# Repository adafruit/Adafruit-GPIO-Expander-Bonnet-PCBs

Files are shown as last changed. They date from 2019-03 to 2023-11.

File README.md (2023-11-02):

## Adafruit GPIO Expander Bonnet PCB

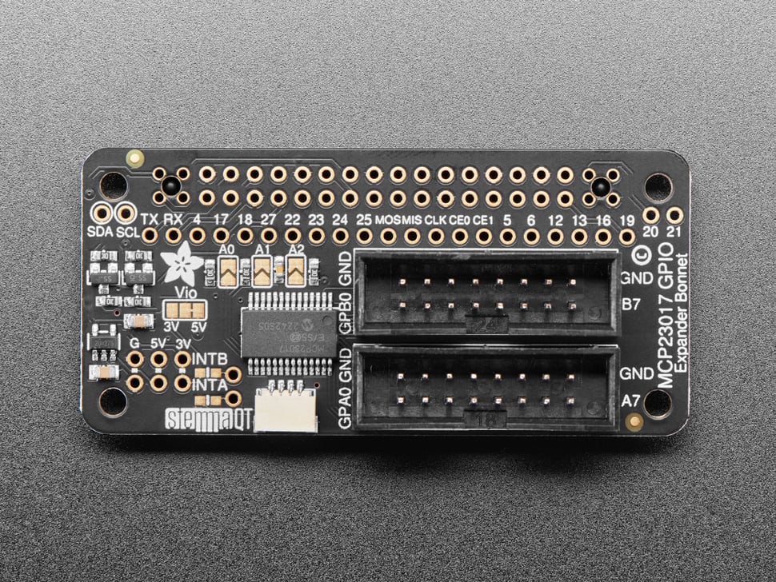
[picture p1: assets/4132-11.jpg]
<a href="http://www.adafruit.com/products/4132"><br/>
Click here to purchase one from the Adafruit shop</a>

PCB files for the Adafruit GPIO Expander Bonnet. Format is EagleCAD schematic and board layout
* https://www.adafruit.com/product/4132

### Description

The Raspberry Pi is an amazing single board computer - and one of the best parts is that GPIO connector! 40 pins of digital goodness you can twiddle to control LEDs, sensors, buttons, radios, displays - just about any device you can imagine. This Adafruit GPIO Expander Bonnet will give you even more digital deliciousness - 16 more digital input/output pins are yours for any desire you have. The outputs are grouped into two 16-pin connectors that have a matching ground pin. You can set each pin to be a digital output (high or low) or as an input, with an internal pull-up if you like!

Simply pop the Bonnet on top of your Pi, the circuitry connects to the SDA/SCL I2C pins for control. The MCP23017 chip converts our Python commands to pin instructions.

When used as an output, each pin can supply up to 20mA (current clamped) - so you can drive LEDs directly. The datasheet recommends you keep the total current draw to under 125mA for the whole chip. We set up the expander chip for 5V logic by default (the I2C is level shifted so that's 3V logic). We did that so you can drive white, blue or green LEDs that sometimes aren't too happy with 3.3V logic. Or, you can cut/solder a jumper to change it to 3.3V logic.

When used as an input, you can set up a pull-up resistor so buttons and switches don't need extra resistors - just wire the pin to one side and ground to the other! There's interrupt capabilities on the chip, and two IRQ pins (INTA and INTB) you can solder a wire to, if you want to have a quick way of telling if any of the GPIO's changed.

By soldering close the address select jumpers, you can change the address from 0x20 up to 0x27. So, if you wanted to, you could have up to 8 bonnets for 128 total GPIO.

Comes as an assembled and tested Bonnet with slim 2x20 header connector on the bottom. We provide 2 sets of 16-pin IDC sockets, you can solder these in or leave them off for a slim setup. [Follow our guide to use our CircuitPython library with Python 3 for fast and easy setup and configuration, you'll be running in under 5 minutes.](https://learn.adafruit.com/gpio-expander-bonnet/overview)

<b>As of October 31, 2023</b> - We've added an on-board Stemma QT port for easy plug-n-play of I2C sensors and devices. The board also now comes with the two IDC socket headers pre-soldered. Lastly, we've also updated it with Adafruit Pinguin to make a lovely and legible silkscreen

### License

Adafruit invests time and resources providing this open source design, please support Adafruit and open-source hardware by purchasing products from [Adafruit](https://www.adafruit.com)!

Designed by Limor Fried/Ladyada for Adafruit Industries.

Creative Commons Attribution/Share-Alike, all text above must be included in any redistribution. See license.txt for additional details.

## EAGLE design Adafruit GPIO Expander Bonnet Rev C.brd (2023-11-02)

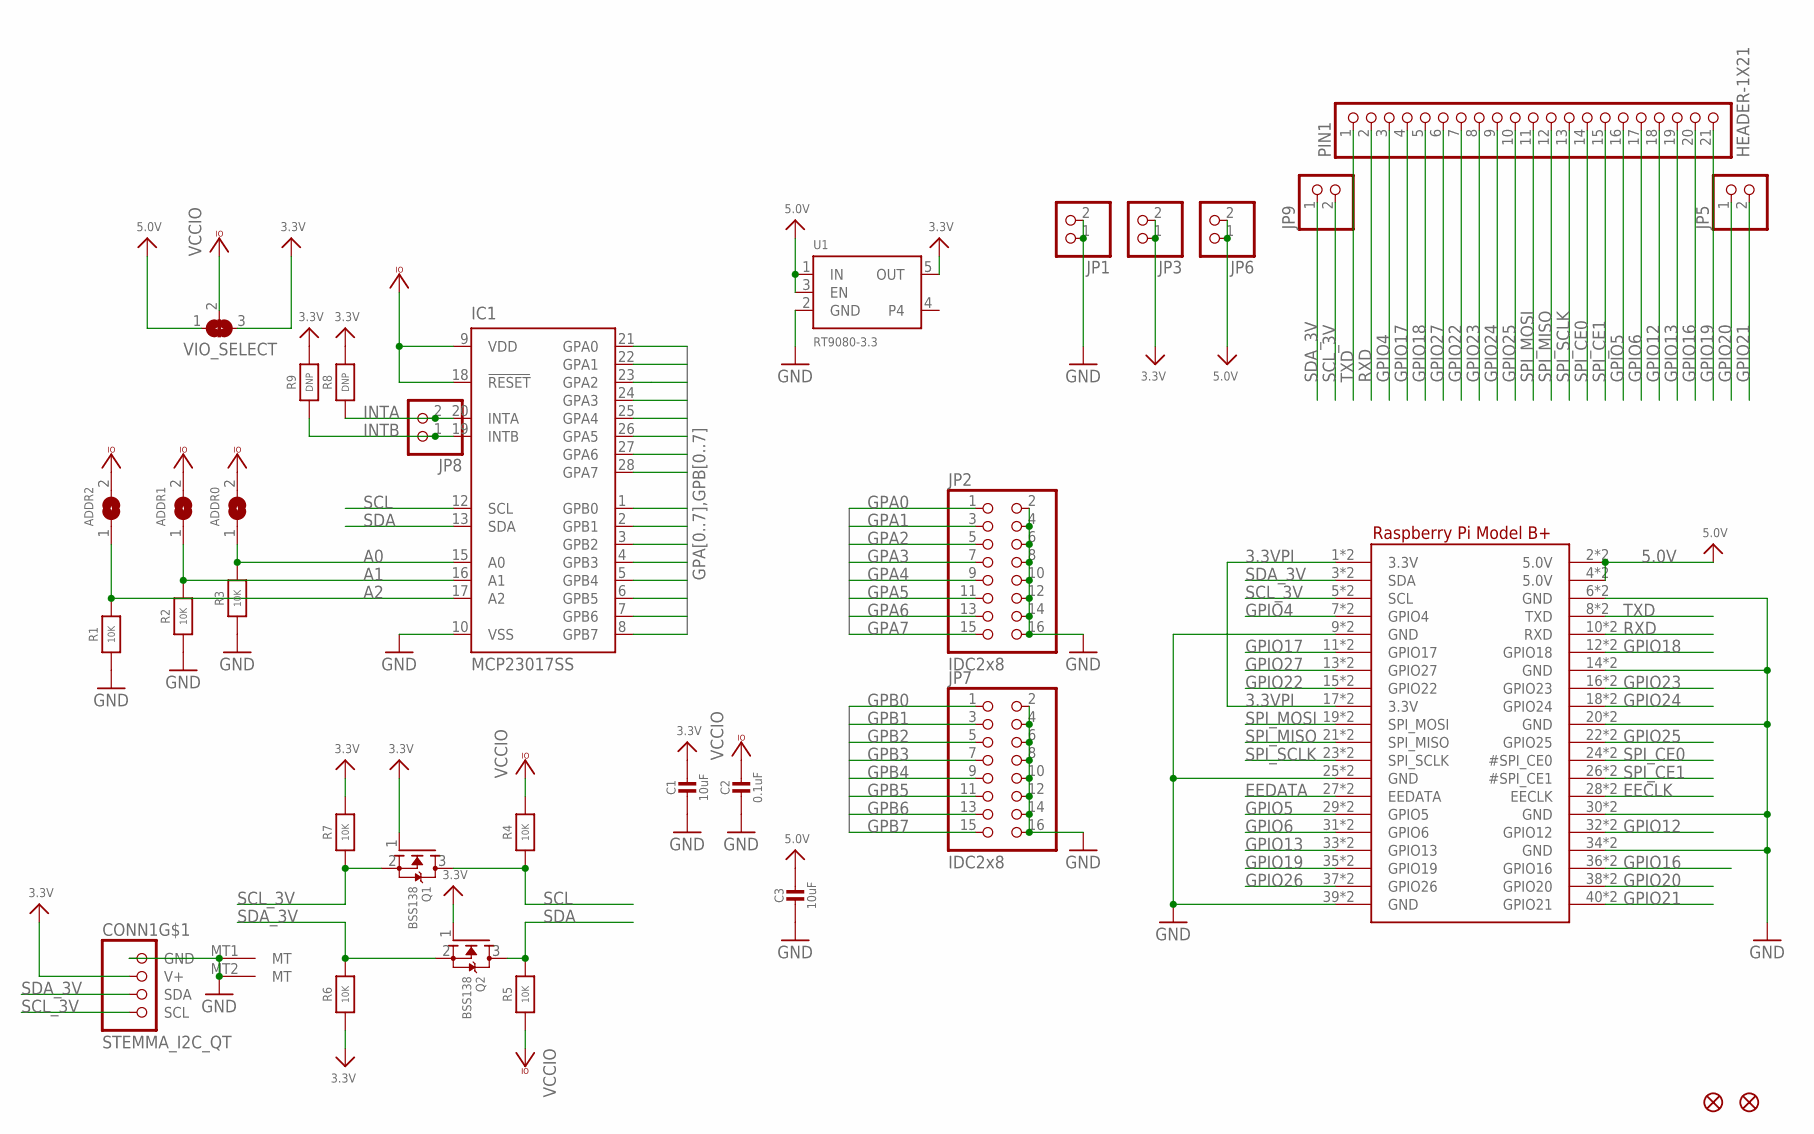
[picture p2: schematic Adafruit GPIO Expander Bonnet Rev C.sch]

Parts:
ADDR0, ADDR1, ADDR2: SOLDERJUMPER; SOLDERJUMPER_ARROW_NOPASTE
C1, C3: 10uF; 0805-NO
C2: 0.1uF; 0603-NO
CONN1: STEMMA_I2C_QT; JST_SH4
FID1, FID2: FIDUCIAL_1MM
IC1: MCP23017SS; SSOP28
JP1, JP3, JP5, JP6, JP8, JP9: HEADER-1X2ROUND; 1X02_ROUND
JP2, JP7: IDC2x8; 2X08_SHROUDED
PIN1: HEADER-1X21; 1X21_ROUND_70MIL
Q1, Q2: BSS138; SOT23-WIDE
R1, R2, R3, R4, R5, R6, R7: 10K; 0603-NO
R8, R9: DNP; 0603-NO
RPI1: RASPBERRYPI_BPLUS_BONNET_THMSMT; PI_BONNET_THMSMT
U1: RT9080-3.3; SOT23-5; JLC_ROTATION 0
VIO_SELECT: SOLDERJUMPER_2WAY; SOLDERJUMPER_2WAY_OPEN_NOPASTE

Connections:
3.3V: C1.1, CONN1.2 (V+), JP3.1, JP3.2, Q1.1 (G), Q2.1 (G), R6.1, R7.2, R8.2, R9.2, U1.5 (OUT), VIO_SELECT.3
3.3VPI: RPI1.1 (3.3V), RPI1.17 (3.3V), RPI1.S1 (3.3V), RPI1.S17 (3.3V)
5.0V: C3.1, JP6.1, JP6.2, RPI1.2 (5.0V), RPI1.4 (5.0V), RPI1.S2 (5.0V), RPI1.S4 (5.0V), U1.1 (IN), U1.3 (EN), VIO_SELECT.1
A0: ADDR0.1, IC1.15 (A0), R3.2
A1: ADDR1.1, IC1.16 (A1), R2.2
A2: ADDR2.1, IC1.17 (A2), R1.2
EECLK: RPI1.28 (EECLK), RPI1.S28 (EECLK)
EEDATA: RPI1.27 (EEDATA), RPI1.S27 (EEDATA)
GND: C1.2, C2.2, C3.2, CONN1.1 (GND), CONN1.MT1 (MT), CONN1.MT2 (MT), IC1.10 (VSS), JP1.1, JP1.2, JP2.2, JP2.4, JP2.6, JP2.8, JP2.10, JP2.12, JP2.14, JP2.16, JP7.2, JP7.4, JP7.6, JP7.8, JP7.10, JP7.12, JP7.14, JP7.16, R1.1, R2.1, R3.1, RPI1.6 (GND), RPI1.9 (GND), RPI1.14 (GND), RPI1.20 (GND), RPI1.25 (GND), RPI1.30 (GND), RPI1.34 (GND), RPI1.39 (GND), RPI1.S6 (GND), RPI1.S9 (GND), RPI1.S14 (GND), RPI1.S20 (GND), RPI1.S25 (GND), RPI1.S30 (GND), RPI1.S34 (GND), RPI1.S39 (GND), U1.2 (GND)
GPA0: IC1.21 (GPA0), JP2.1
GPA1: IC1.22 (GPA1), JP2.3
GPA2: IC1.23 (GPA2), JP2.5
GPA3: IC1.24 (GPA3), JP2.7
GPA4: IC1.25 (GPA4), JP2.9
GPA5: IC1.26 (GPA5), JP2.11
GPA6: IC1.27 (GPA6), JP2.13
GPA7: IC1.28 (GPA7), JP2.15
GPB0: IC1.1 (GPB0), JP7.1
GPB1: IC1.2 (GPB1), JP7.3
GPB2: IC1.3 (GPB2), JP7.5
GPB3: IC1.4 (GPB3), JP7.7
GPB4: IC1.5 (GPB4), JP7.9
GPB5: IC1.6 (GPB5), JP7.11
GPB6: IC1.7 (GPB6), JP7.13
GPB7: IC1.8 (GPB7), JP7.15
GPIO4: PIN1.3, RPI1.7 (GPIO4), RPI1.S7 (GPIO4)
GPIO5: PIN1.16, RPI1.29 (GPIO5), RPI1.S29 (GPIO5)
GPIO6: PIN1.17, RPI1.31 (GPIO6), RPI1.S31 (GPIO6)
GPIO12: PIN1.18, RPI1.32 (GPIO12), RPI1.S32 (GPIO12)
GPIO13: PIN1.19, RPI1.33 (GPIO13), RPI1.S33 (GPIO13)
GPIO16: PIN1.20, RPI1.36 (GPIO16), RPI1.S36 (GPIO16)
GPIO17: PIN1.4, RPI1.11 (GPIO17), RPI1.S11 (GPIO17)
GPIO18: PIN1.5, RPI1.12 (GPIO18), RPI1.S12 (GPIO18)
GPIO19: PIN1.21, RPI1.35 (GPIO19), RPI1.S35 (GPIO19)
GPIO20: JP5.1, RPI1.38 (GPIO20), RPI1.S38 (GPIO20)
GPIO21: JP5.2, RPI1.40 (GPIO21), RPI1.S40 (GPIO21)
GPIO22: PIN1.7, RPI1.15 (GPIO22), RPI1.S15 (GPIO22)
GPIO23: PIN1.8, RPI1.16 (GPIO23), RPI1.S16 (GPIO23)
GPIO24: PIN1.9, RPI1.18 (GPIO24), RPI1.S18 (GPIO24)
GPIO25: PIN1.10, RPI1.22 (GPIO25), RPI1.S22 (GPIO25)
GPIO26: RPI1.37 (GPIO26), RPI1.S37 (GPIO26)
GPIO27: PIN1.6, RPI1.13 (GPIO27), RPI1.S13 (GPIO27)
INTA: IC1.20 (INTA), JP8.2, R8.1
INTB: IC1.19 (INTB), JP8.1, R9.1
RXD: PIN1.2, RPI1.10 (RXD), RPI1.S10 (RXD)
SCL: IC1.12 (SCL), Q1.3 (D), R4.1
SCL_3V: CONN1.4 (SCL), JP9.2, Q1.2 (S), R7.1, RPI1.5 (SCL), RPI1.S5 (SCL)
SDA: IC1.13 (SDA), Q2.3 (D), R5.2
SDA_3V: CONN1.3 (SDA), JP9.1, Q2.2 (S), R6.2, RPI1.3 (SDA), RPI1.S3 (SDA)
SPI_CE0: PIN1.14, RPI1.24 (#SPI_CE0), RPI1.S24 (#SPI_CE0)
SPI_CE1: PIN1.15, RPI1.26 (#SPI_CE1), RPI1.S26 (#SPI_CE1)
SPI_MISO: PIN1.12, RPI1.21 (SPI_MISO), RPI1.S21 (SPI_MISO)
SPI_MOSI: PIN1.11, RPI1.19 (SPI_MOSI), RPI1.S19 (SPI_MOSI)
SPI_SCLK: PIN1.13, RPI1.23 (SPI_SCLK), RPI1.S23 (SPI_SCLK)
TXD: PIN1.1, RPI1.8 (TXD), RPI1.S8 (TXD)
VCCIO: ADDR0.2, ADDR1.2, ADDR2.2, C2.1, IC1.9 (VDD), IC1.18 (!RESET), R4.2, R5.1, VIO_SELECT.2

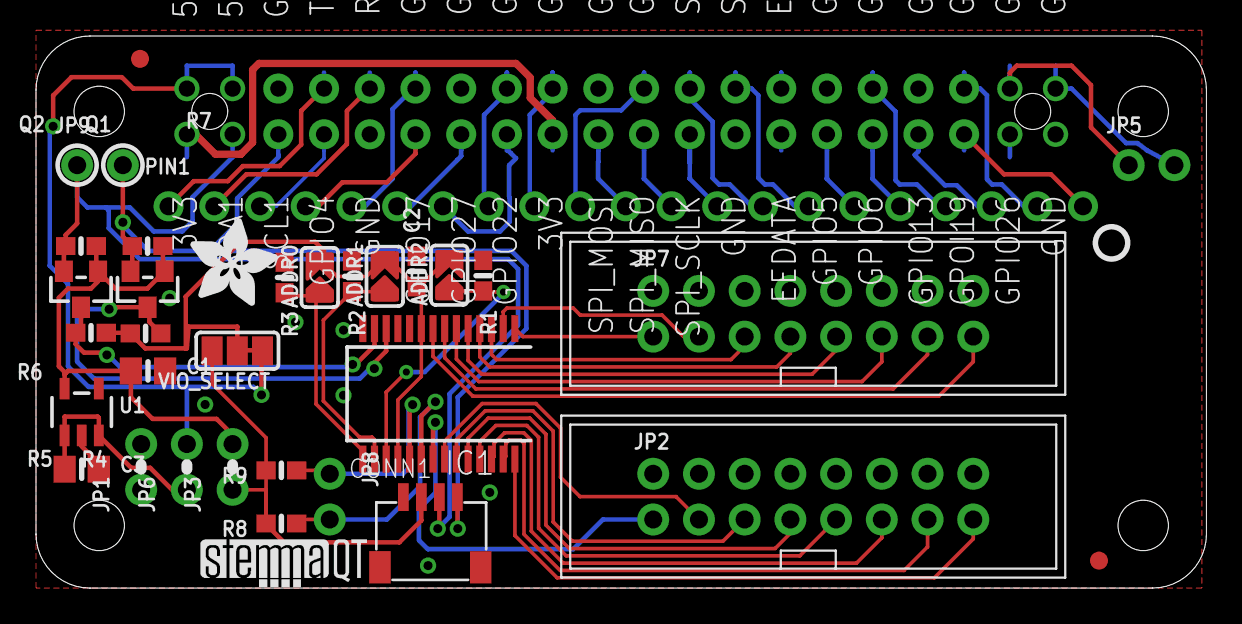
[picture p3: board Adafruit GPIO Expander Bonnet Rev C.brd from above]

Board: 2 copper layers, 65.0 x 30.7 mm, 100 parts (0 on the bottom side), 56 nets.

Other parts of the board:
PLABEL0: PLABEL0
PLABEL1: PLABEL1
PLABEL2: PLABEL2
PLABEL3: PLABEL3
PLABEL4: PLABEL4
PLABEL5: PLABEL5
PLABEL6: PLABEL6
PLABEL7: PLABEL7
PLABEL8: PLABEL8
PLABEL9: PLABEL9
PLABEL10: PLABEL10
PLABEL11: PLABEL11
PLABEL12: PLABEL12
PLABEL13: PLABEL13
PLABEL14: PLABEL14
PLABEL15: PLABEL15
PLABEL16: PLABEL16
PLABEL17: PLABEL17
PLABEL18: PLABEL18
PLABEL19: PLABEL19
PLABEL20: PLABEL20
PLABEL21: PLABEL21
PLABEL22: PLABEL22
PLABEL23: PLABEL23
PLABEL24: PLABEL24
PLABEL25: PLABEL25
PLABEL26: PLABEL26
PLABEL27: PLABEL27
PLABEL28: PLABEL28
PLABEL29: PLABEL29
PLABEL30: PLABEL30
PLABEL31: PLABEL31
PLABEL32: PLABEL32
PLABEL33: PLABEL33
PLABEL34: PLABEL34
PLABEL35: PLABEL35
PLABEL36: PLABEL36
PLABEL37: PLABEL37
PLABEL38: PLABEL38
PLABEL39: PLABEL39
PLABEL40: PLABEL40
PLABEL41: PLABEL41
PLABEL42: PLABEL42
PLABEL43: PLABEL43
PLABEL44: PLABEL44
PLABEL45: PLABEL45
PLABEL46: PLABEL46
PLABEL47: PLABEL47
PLABEL48: PLABEL48
PLABEL49: PLABEL49
PLABEL50: PLABEL50
PLABEL51: PLABEL51
PLABEL52: PLABEL52
PLABEL53: PLABEL53
PLABEL54: PLABEL54
PLABEL55: PLABEL55
PLABEL56: PLABEL56
PLABEL57: PLABEL57
PLABEL58: PLABEL58
PLABEL59: PLABEL59
PLABEL60: PLABEL60
PLABEL61: PLABEL61
PLABEL62: PLABEL62
PLABEL63: PLABEL63
U$12: ADAFRUIT_5MM
U$13: PCBFEAT-REV-040
U$19: STEMMAQT

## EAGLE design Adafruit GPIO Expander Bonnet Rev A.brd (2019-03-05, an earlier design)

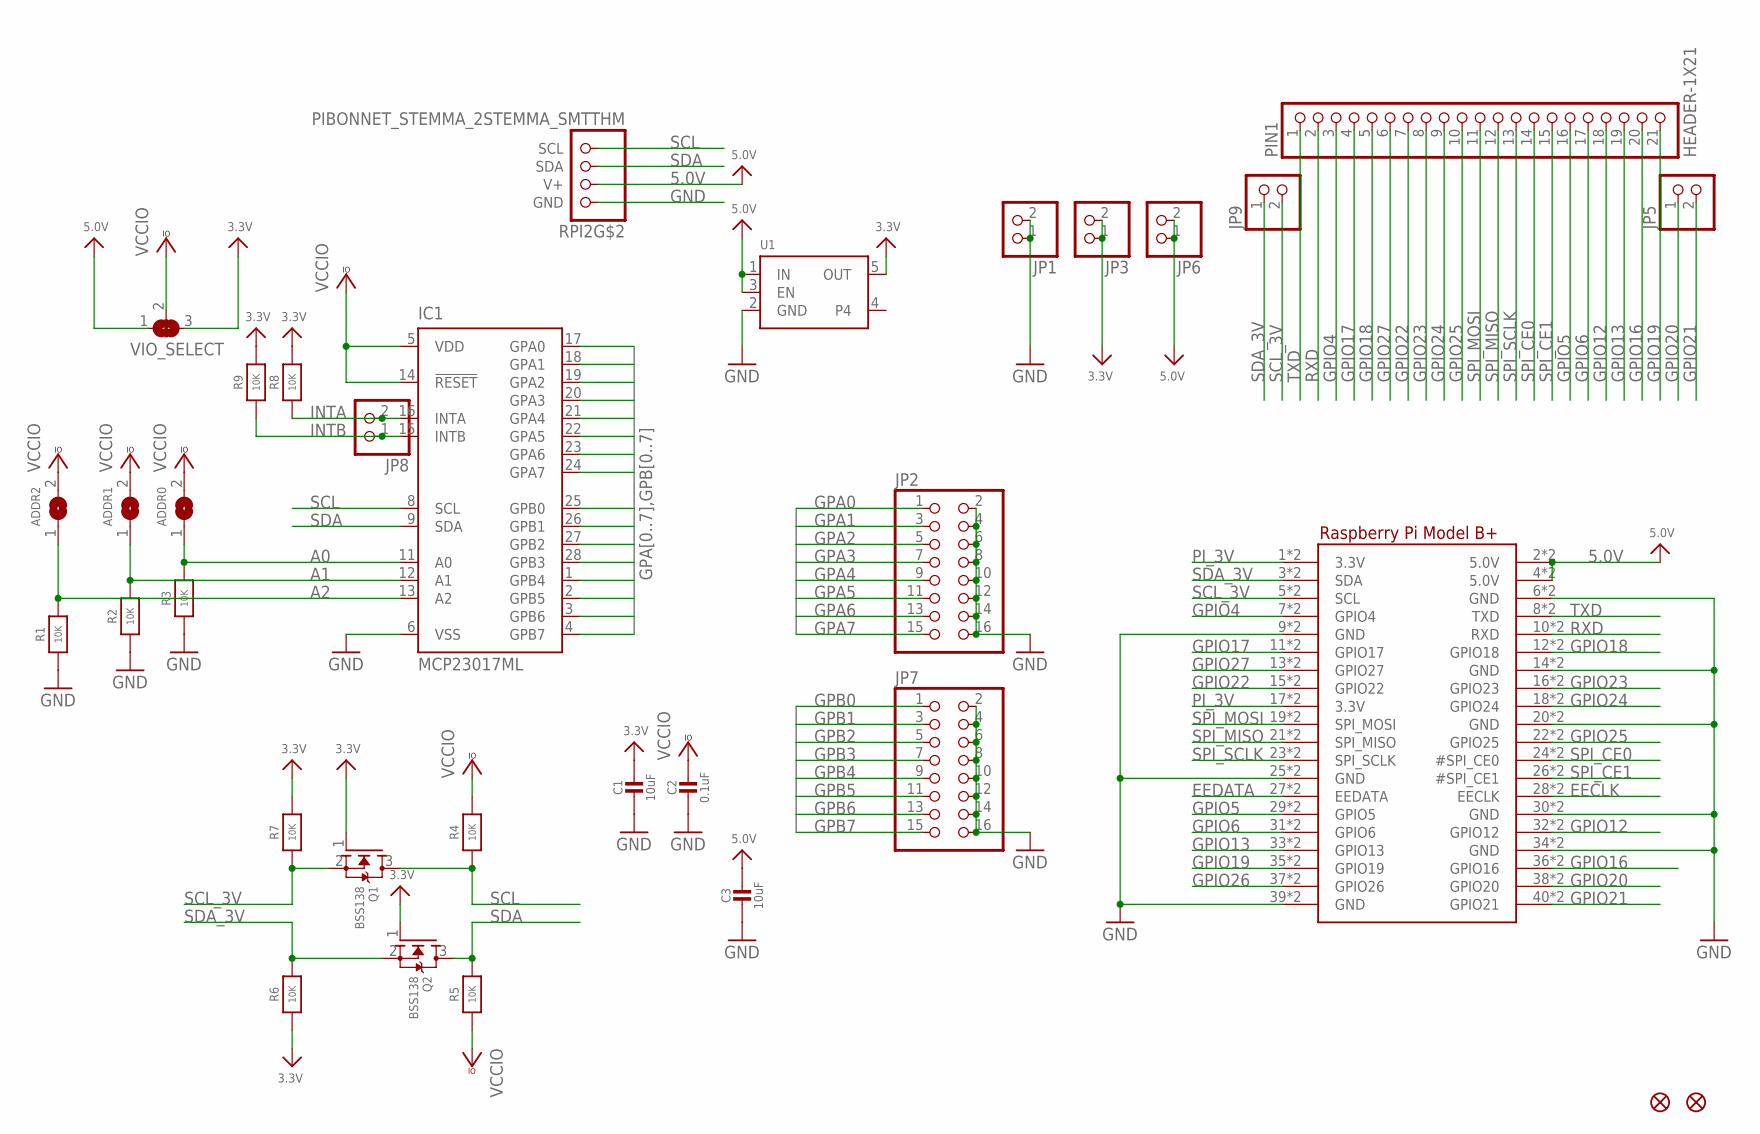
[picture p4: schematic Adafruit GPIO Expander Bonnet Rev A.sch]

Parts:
ADDR0, ADDR1, ADDR2: SOLDERJUMPER; SOLDERJUMPER_ARROW_NOPASTE
C1, C3: 10uF; 0805-NO
C2: 0.1uF; 0603-NO
FID1, FID2: FIDUCIAL_1MM
IC1: MCP23017ML; QFN28-ML_6X6MM
JP1, JP3, JP5, JP6, JP8, JP9: HEADER-1X2ROUND; 1X02_ROUND
JP2, JP7: HEADER-2X8_SHROUDED; 2X08_SHROUDED
PIN1: HEADER-1X21; 1X21_ROUND_70MIL
Q1, Q2: BSS138; SOT23-WIDE
R1, R2, R3, R4, R5, R6, R7, R8, R9: 10K; 0603-NO
RPI2: PIBONNET_STEMMA_2STEMMA_SMTTHM; PI_BONNET_2STEMMA_SMT
U1: VREG_SOT23-5; SOT23-5
VIO_SELECT: SOLDERJUMPER_2WAY; SOLDERJUMPER_2WAY_OPEN_NOPASTE

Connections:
3.3V: C1.1, JP3.1, JP3.2, Q1.1 (G), Q2.1 (G), R6.1, R7.2, R8.2, R9.2, U1.5 (OUT), VIO_SELECT.3
5.0V: C3.1, JP6.1, JP6.2, RPI2.2 (5.0V), RPI2.4 (5.0V), RPI2.S2 (5.0V), RPI2.S4 (5.0V), RPI2.V+, RPI2.V+1 (V+), U1.1 (IN), U1.3 (EN), VIO_SELECT.1
A0: ADDR0.1, IC1.11 (A0), R3.2
A1: ADDR1.1, IC1.12 (A1), R2.2
A2: ADDR2.1, IC1.13 (A2), R1.2
EECLK: RPI2.28 (EECLK), RPI2.S28 (EECLK)
EEDATA: RPI2.27 (EEDATA), RPI2.S27 (EEDATA)
GND: C1.2, C2.2, C3.2, IC1.6 (VSS), JP1.1, JP1.2, JP2.2, JP2.4, JP2.6, JP2.8, JP2.10, JP2.12, JP2.14, JP2.16, JP7.2, JP7.4, JP7.6, JP7.8, JP7.10, JP7.12, JP7.14, JP7.16, R1.1, R2.1, R3.1, RPI2.6 (GND), RPI2.9 (GND), RPI2.14 (GND), RPI2.20 (GND), RPI2.25 (GND), RPI2.30 (GND), RPI2.34 (GND), RPI2.39 (GND), RPI2.GND, RPI2.GND1 (GND), RPI2.S6 (GND), RPI2.S9 (GND), RPI2.S14 (GND), RPI2.S20 (GND), RPI2.S25 (GND), RPI2.S30 (GND), RPI2.S34 (GND), RPI2.S39 (GND), U1.2 (GND)
GPA0: IC1.17 (GPA0), JP2.1
GPA1: IC1.18 (GPA1), JP2.3
GPA2: IC1.19 (GPA2), JP2.5
GPA3: IC1.20 (GPA3), JP2.7
GPA4: IC1.21 (GPA4), JP2.9
GPA5: IC1.22 (GPA5), JP2.11
GPA6: IC1.23 (GPA6), JP2.13
GPA7: IC1.24 (GPA7), JP2.15
GPB0: IC1.25 (GPB0), JP7.1
GPB1: IC1.26 (GPB1), JP7.3
GPB2: IC1.27 (GPB2), JP7.5
GPB3: IC1.28 (GPB3), JP7.7
GPB4: IC1.1 (GPB4), JP7.9
GPB5: IC1.2 (GPB5), JP7.11
GPB6: IC1.3 (GPB6), JP7.13
GPB7: IC1.4 (GPB7), JP7.15
GPIO4: PIN1.3, RPI2.7 (GPIO4), RPI2.S7 (GPIO4)
GPIO5: PIN1.16, RPI2.29 (GPIO5), RPI2.S29 (GPIO5)
GPIO6: PIN1.17, RPI2.31 (GPIO6), RPI2.S31 (GPIO6)
GPIO12: PIN1.18, RPI2.32 (GPIO12), RPI2.S32 (GPIO12)
GPIO13: PIN1.19, RPI2.33 (GPIO13), RPI2.S33 (GPIO13)
GPIO16: PIN1.20, RPI2.36 (GPIO16), RPI2.S36 (GPIO16)
GPIO17: PIN1.4, RPI2.11 (GPIO17), RPI2.S11 (GPIO17)
GPIO18: PIN1.5, RPI2.12 (GPIO18), RPI2.S12 (GPIO18)
GPIO19: PIN1.21, RPI2.35 (GPIO19), RPI2.S35 (GPIO19)
GPIO20: JP5.1, RPI2.38 (GPIO20), RPI2.S38 (GPIO20)
GPIO21: JP5.2, RPI2.40 (GPIO21), RPI2.S40 (GPIO21)
GPIO22: PIN1.7, RPI2.15 (GPIO22), RPI2.S15 (GPIO22)
GPIO23: PIN1.8, RPI2.16 (GPIO23), RPI2.S16 (GPIO23)
GPIO24: PIN1.9, RPI2.18 (GPIO24), RPI2.S18 (GPIO24)
GPIO25: PIN1.10, RPI2.22 (GPIO25), RPI2.S22 (GPIO25)
GPIO26: RPI2.37 (GPIO26), RPI2.S37 (GPIO26)
GPIO27: PIN1.6, RPI2.13 (GPIO27), RPI2.S13 (GPIO27)
INTA: IC1.16 (INTA), JP8.2, R8.1
INTB: IC1.15 (INTB), JP8.1, R9.1
PI_3V: RPI2.1 (3.3V), RPI2.17 (3.3V), RPI2.S1 (3.3V), RPI2.S17 (3.3V)
RXD: PIN1.2, RPI2.10 (RXD), RPI2.S10 (RXD)
SCL: IC1.8 (SCL), Q1.3 (D), R4.1, RPI2.SCL, RPI2.SCL1 (SCL)
SCL_3V: JP9.2, Q1.2 (S), R7.1, RPI2.5 (SCL), RPI2.S5 (SCL)
SDA: IC1.9 (SDA), Q2.3 (D), R5.2, RPI2.SDA, RPI2.SDA1 (SDA)
SDA_3V: JP9.1, Q2.2 (S), R6.2, RPI2.3 (SDA), RPI2.S3 (SDA)
SPI_CE0: PIN1.14, RPI2.24 (#SPI_CE0), RPI2.S24 (#SPI_CE0)
SPI_CE1: PIN1.15, RPI2.26 (#SPI_CE1), RPI2.S26 (#SPI_CE1)
SPI_MISO: PIN1.12, RPI2.21 (SPI_MISO), RPI2.S21 (SPI_MISO)
SPI_MOSI: PIN1.11, RPI2.19 (SPI_MOSI), RPI2.S19 (SPI_MOSI)
SPI_SCLK: PIN1.13, RPI2.23 (SPI_SCLK), RPI2.S23 (SPI_SCLK)
TXD: PIN1.1, RPI2.8 (TXD), RPI2.S8 (TXD)
VCCIO: ADDR0.2, ADDR1.2, ADDR2.2, C2.1, IC1.5 (VDD), IC1.14 (!RESET), R4.2, R5.1, VIO_SELECT.2

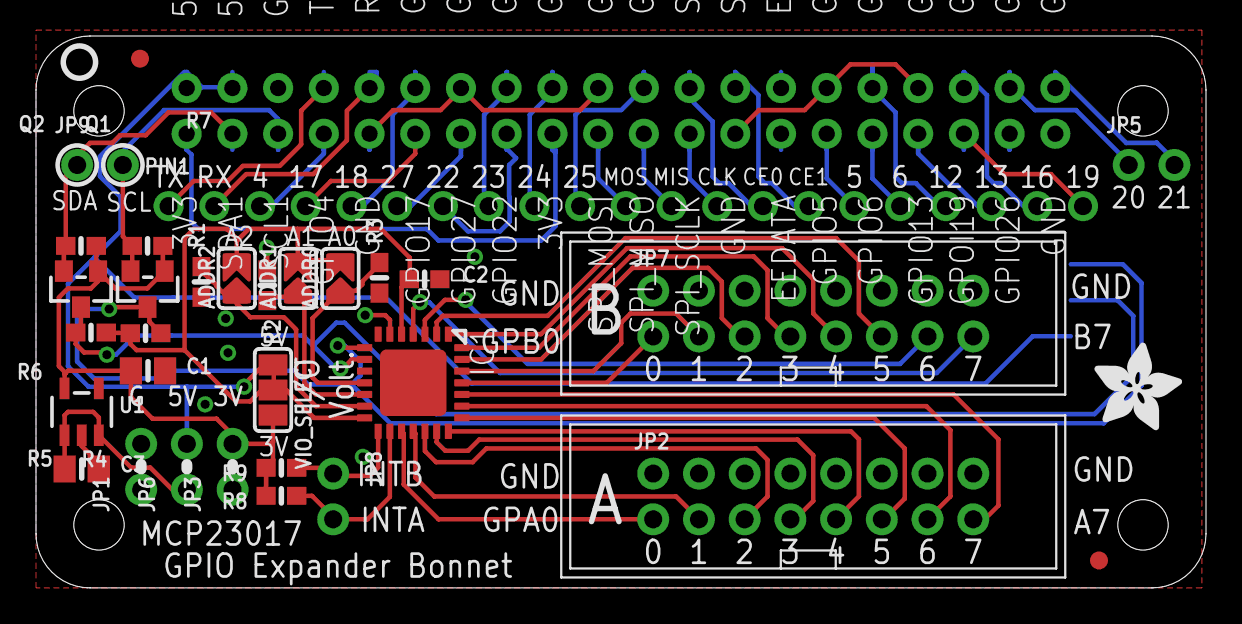
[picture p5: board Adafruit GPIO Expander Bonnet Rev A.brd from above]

Board: 2 copper layers, 65.0 x 30.7 mm, 34 parts (0 on the bottom side), 56 nets.

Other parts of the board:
U$12: ADAFRUIT_5MM
U$13: PCBFEAT-REV-040

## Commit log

2019-03-05 adding board files
    [Adafruit GPIO Expander Bonnet.brd, Adafruit GPIO Expander Bonnet.sch]
2019-07-17 updated to use cookiecutter for pcb repos
2023-11-02 updating for rev C
    [Adafruit GPIO Expander Bonnet Rev A.brd, Adafruit GPIO Expander Bonnet Rev A.sch, Adafruit GPIO Expander Bonnet Rev C.brd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]

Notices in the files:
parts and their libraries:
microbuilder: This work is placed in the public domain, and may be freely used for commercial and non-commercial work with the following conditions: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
